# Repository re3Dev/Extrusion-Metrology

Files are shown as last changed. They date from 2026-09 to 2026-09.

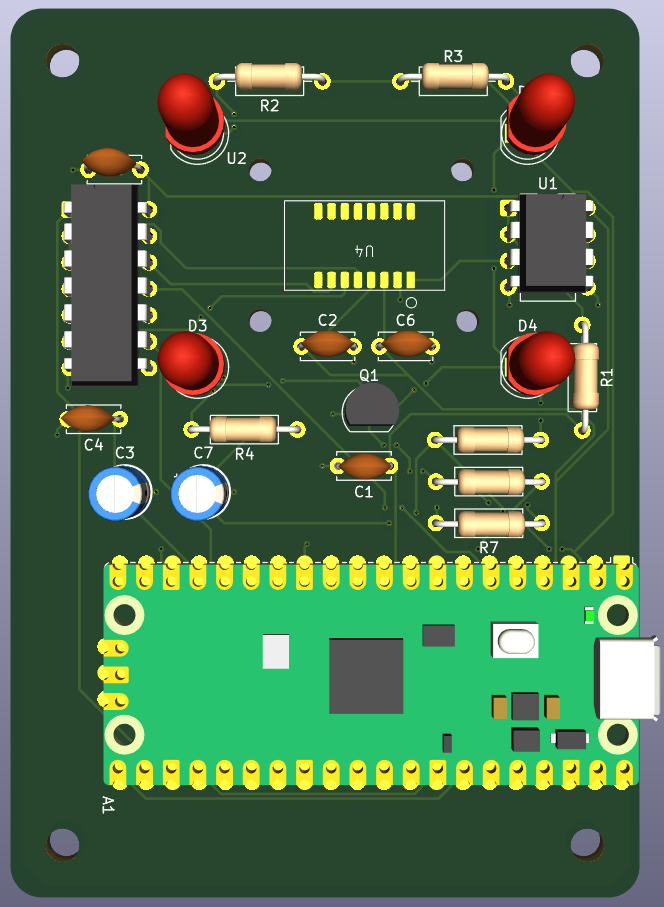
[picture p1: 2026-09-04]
3D-PCB.png

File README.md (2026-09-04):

Copyright © 2026 Mitchell Mashburn All rights reserved.
Source files are made publicly available for review, education, and evaluation. No permission is granted for commercial manufacture, redistribution, or derivative works without written authorization.

# Extrusion-Metrology
PCB with a main purpose of a low-cost, dedicated 1D metrology sensor specifically for a Klipper printer, use controlled illumination to get a high-resolution bead cross-section without running full machine vision, and automate calibration using the printer's existing motion system.

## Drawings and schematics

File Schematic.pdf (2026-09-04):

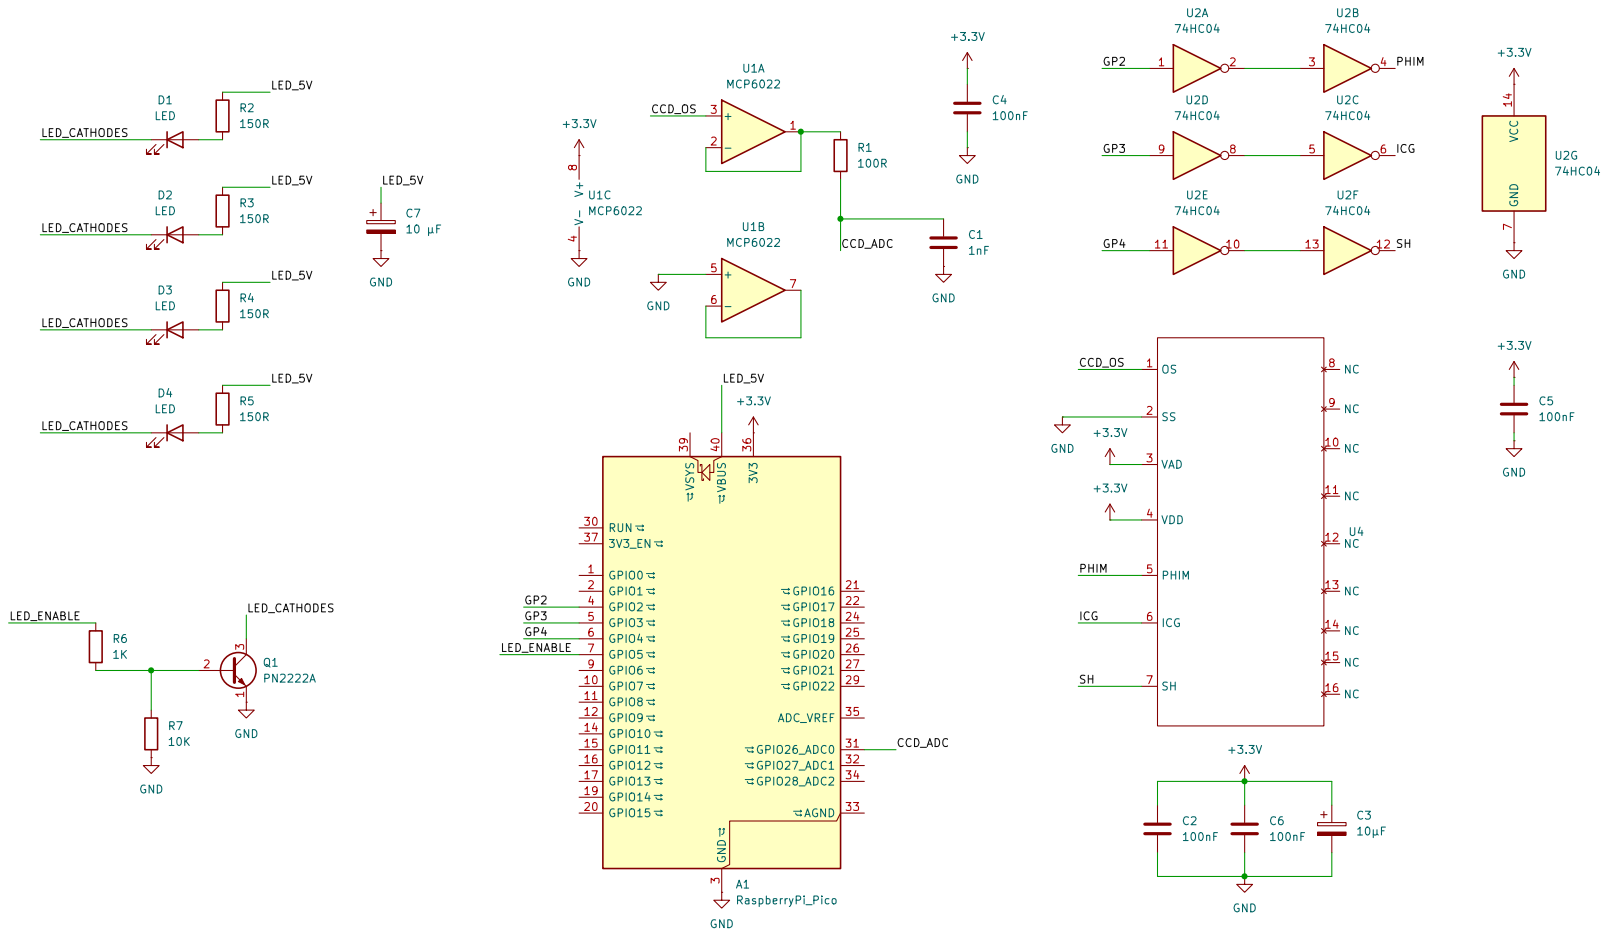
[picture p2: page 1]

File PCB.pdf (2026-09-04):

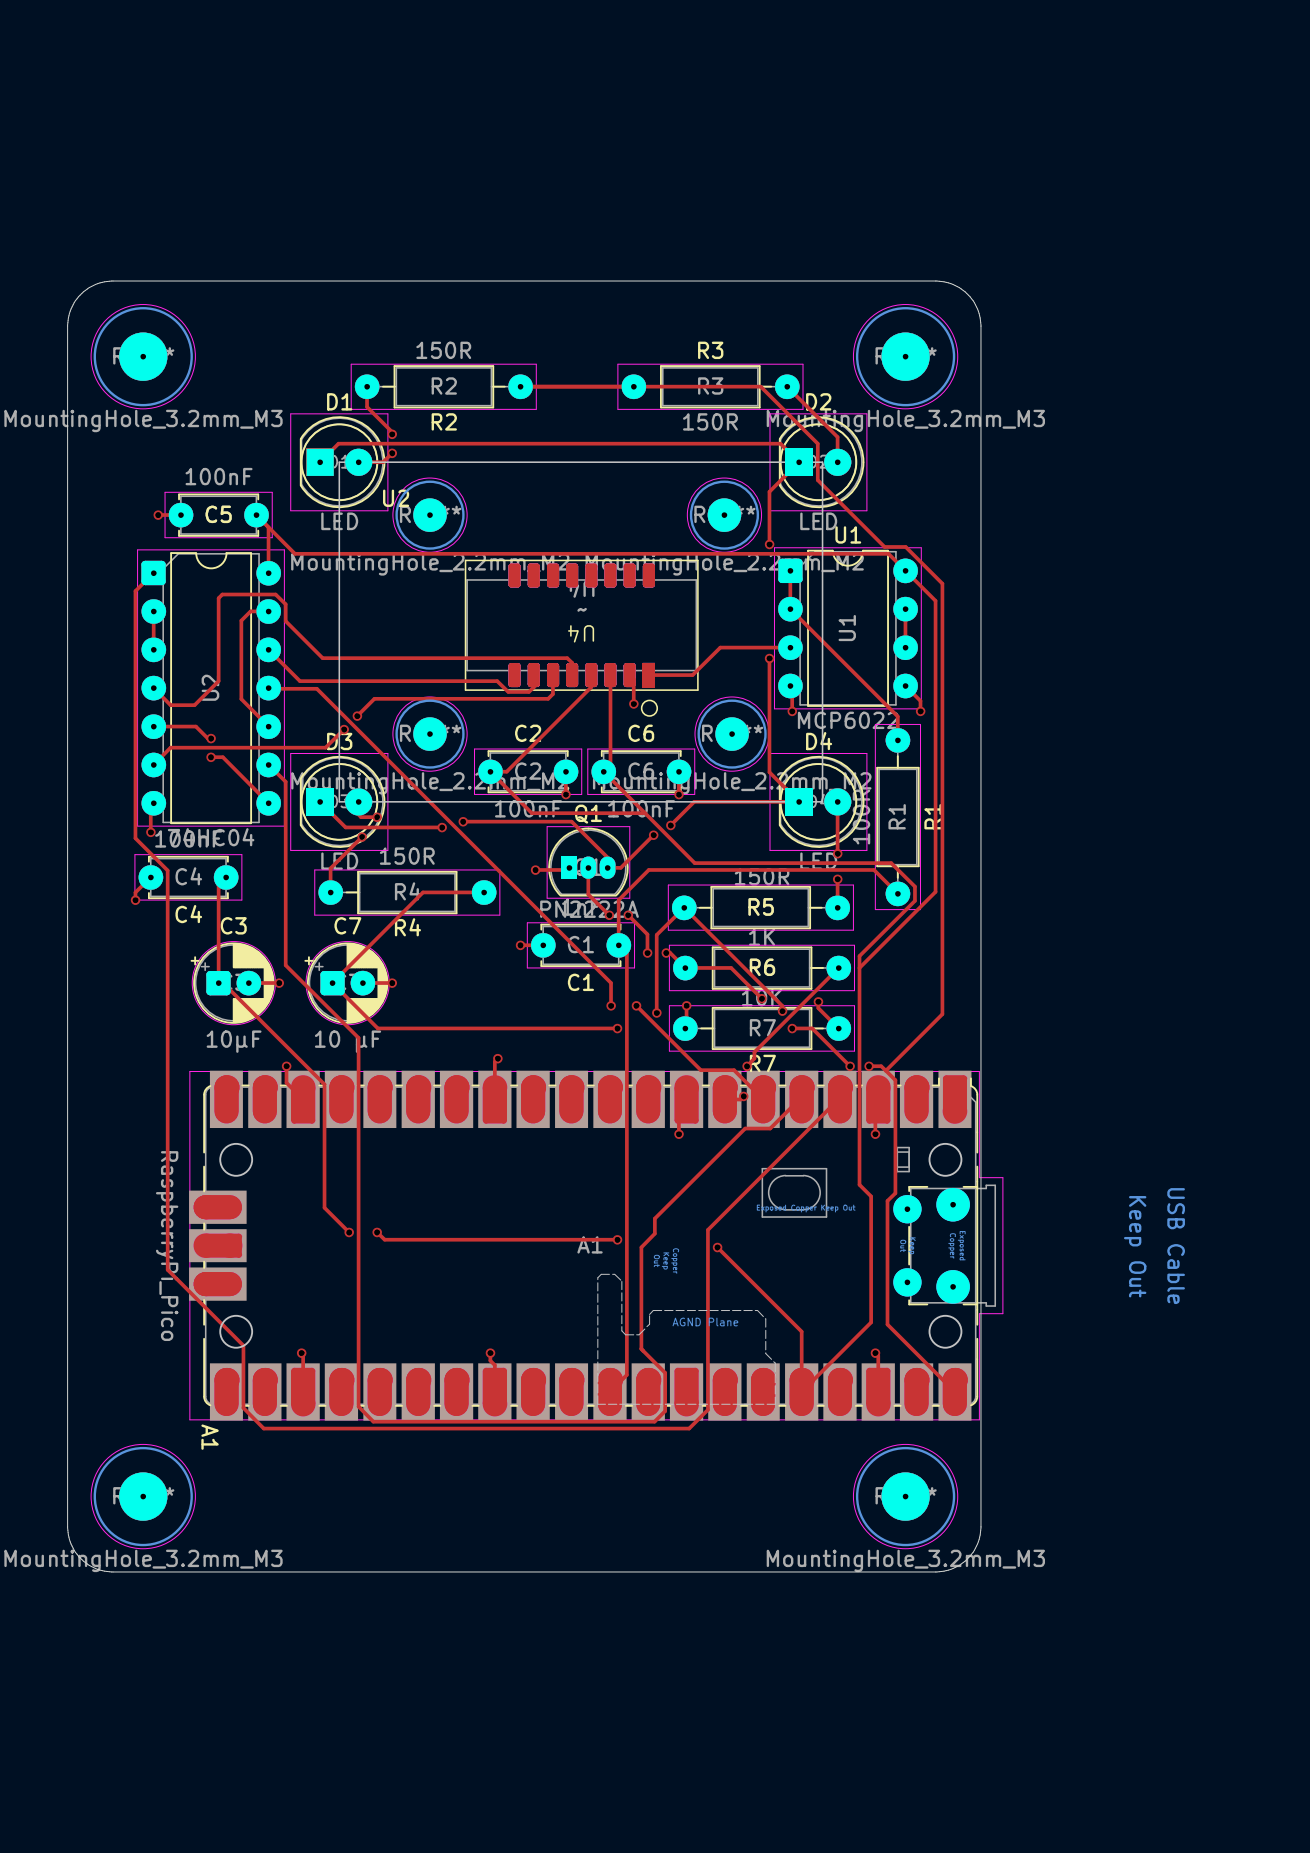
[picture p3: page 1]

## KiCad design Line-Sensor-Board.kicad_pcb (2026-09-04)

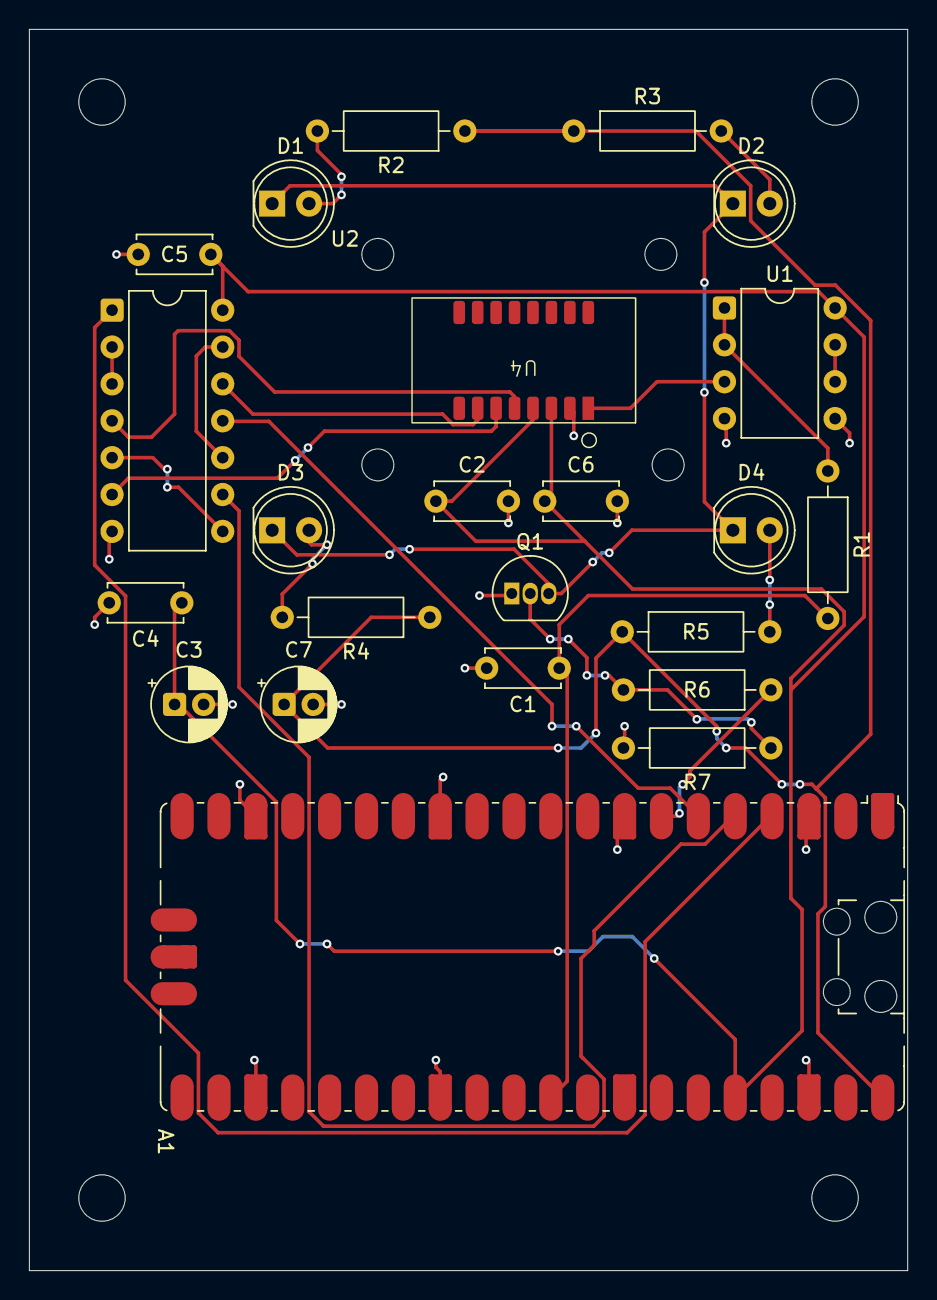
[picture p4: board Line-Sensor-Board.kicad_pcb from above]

Board: 2 copper layers, 60.5 x 85.5 mm, 23 parts (0 on the bottom side), 23 nets.

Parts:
A1: RaspberryPi_Pico; RaspberryPi_Pico_SMD_HandSolder
C1: 1nF; C_Disc_D5.0mm_W2.5mm_P5.00mm
C2, C4, C5, C6: 100nF; C_Disc_D5.0mm_W2.5mm_P5.00mm
C3: 10µF; CP_Radial_D5.0mm_P2.00mm
C7: 10 µF; CP_Radial_D5.0mm_P2.00mm
D1, D2, D3, D4: LED; LED_D5.0mm
Q1: PN2222A; TO-92_Inline
R1: 100R; R_Axial_DIN0207_L6.3mm_D2.5mm_P10.16mm_Horizontal
R2, R3, R4, R5: 150R; R_Axial_DIN0207_L6.3mm_D2.5mm_P10.16mm_Horizontal
R6: 1K; R_Axial_DIN0207_L6.3mm_D2.5mm_P10.16mm_Horizontal
R7: 10K; R_Axial_DIN0207_L6.3mm_D2.5mm_P10.16mm_Horizontal
U1: MCP6022; DIP-8_W7.62mm
U2: 74HC04; DIP-14_W7.62mm
U4: TCD1103GFG_HandSolder

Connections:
+3.3V: A1.36 (3V3), C2.1, C3.1, C4.1, C5.1, C6.1, U1.8 (V+), U2.14 (VCC), U4.3 (VAD), U4.4 (VDD)
/CCD_ADC: A1.31 (GPIO26_ADC0), C1.1, R1.2
/CCD_OS: U1.3 (+), U4.1 (OS)
/GP2: A1.4 (GPIO2), U2.1
/GP3: A1.5 (GPIO3), U2.9
/GP4: A1.6 (GPIO4), U2.11
/ICG: U2.6, U4.6 (ICG)
/LED_5V: A1.40 (VBUS), C7.1, R2.1, R3.1, R4.1, R5.1
/LED_CATHODES: D1.1 (K), D2.1 (K), D3.1 (K), D4.1 (K), Q1.3 (C)
/LED_ENABLE: A1.7 (GPIO5), R6.1
/PHIM: U2.4, U4.5 (PHIM)
/SH: U2.12, U4.7 (SH)
GND: A1.3 (GND), A1.8 (GND), A1.13 (GND), A1.18 (GND), A1.23 (GND), A1.28 (GND), A1.38 (GND), C1.2, C2.2, C3.2, C4.2, C5.2, C6.2, C7.2, Q1.1 (E), R7.2, U1.4 (V-), U1.5 (+), U2.7 (GND), U4.2 (SS)
unnamed: D1.2 (A), R2.2
unnamed: D2.2 (A), R3.2
unnamed: D3.2 (A), R4.2
unnamed: D4.2 (A), R5.2
unnamed: Q1.2 (B), R6.2, R7.1
unnamed: R1.1, U1.1, U1.2 (-)
unnamed: U1.6 (-), U1.7
unnamed: U2.2, U2.3
unnamed: U2.5, U2.8
unnamed: U2.10, U2.13

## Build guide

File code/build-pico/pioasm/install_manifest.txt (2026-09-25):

C:/Users/info/Documents/Extrusion-Metrology/code/build-pico/pioasm-install/pioasm/pioasm.exe
C:/Users/info/Documents/Extrusion-Metrology/code/build-pico/pioasm-install/pioasm/pioasmTargets.cmake
C:/Users/info/Documents/Extrusion-Metrology/code/build-pico/pioasm-install/pioasm/pioasmTargets-release.cmake
C:/Users/info/Documents/Extrusion-Metrology/code/build-pico/pioasm-install/pioasm/pioasmConfig.cmake
C:/Users/info/Documents/Extrusion-Metrology/code/build-pico/pioasm-install/pioasm/pioasmConfigVersion.cmake

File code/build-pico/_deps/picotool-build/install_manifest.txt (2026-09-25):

C:/Users/info/Documents/Extrusion-Metrology/code/build-pico/_deps/picotool/picotool.exe
C:/Users/info/Documents/Extrusion-Metrology/code/build-pico/_deps/picotool/picotoolTargets.cmake
C:/Users/info/Documents/Extrusion-Metrology/code/build-pico/_deps/picotool/picotoolTargets-release.cmake
C:/Users/info/Documents/Extrusion-Metrology/code/build-pico/_deps/picotool/picotoolConfig.cmake
C:/Users/info/Documents/Extrusion-Metrology/code/build-pico/_deps/picotool/picotoolConfigVersion.cmake
C:/Users/info/Documents/Extrusion-Metrology/code/build-pico/_deps/picotool/enc_bootloader.elf
C:/Users/info/Documents/Extrusion-Metrology/code/build-pico/_deps/picotool/enc_bootloader_mbedtls.elf

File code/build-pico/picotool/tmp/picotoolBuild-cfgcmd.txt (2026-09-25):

cmd='C:/Program Files/CMake/bin/cmake.exe;--no-warn-unused-cli;-DCMAKE_MAKE_PROGRAM:FILEPATH=C:/Strawberry/c/bin/ninja.exe;-DPICO_SDK_PATH:FILEPATH=C:/Users/info/.pico-sdk/sdk/2.2.0;-DPICOTOOL_NO_LIBUSB=1;-DPICOTOOL_FLAT_INSTALL=1;-DCMAKE_INSTALL_PREFIX=C:/Users/info/Documents/Extrusion-Metrology/code/build-pico/_deps;-DCMAKE_RULE_MESSAGES=OFF;-DCMAKE_INSTALL_MESSAGE=NEVER;-GNinja;-S;<SOURCE_DIR><SOURCE_SUBDIR>;-B;<BINARY_DIR>'

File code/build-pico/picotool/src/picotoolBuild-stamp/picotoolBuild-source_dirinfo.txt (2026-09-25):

# This is a generated file and its contents are an internal implementation detail.
# The download step will be re-executed if anything in this file changes.
# No other meaning or use of this file is supported.

method=source_dir
command=
source_dir=C:/Users/info/Documents/Extrusion-Metrology/code/build-pico/_deps/picotool-src
work_dir=

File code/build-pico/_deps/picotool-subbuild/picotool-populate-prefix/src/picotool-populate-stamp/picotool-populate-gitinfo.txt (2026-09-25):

# This is a generated file and its contents are an internal implementation detail.
# The download step will be re-executed if anything in this file changes.
# No other meaning or use of this file is supported.

method=git
command=C:/Program Files/CMake/bin/cmake.exe;-DCMAKE_MESSAGE_LOG_LEVEL=VERBOSE;-P;C:/Users/info/Documents/Extrusion-Metrology/code/build-pico/_deps/picotool-subbuild/picotool-populate-prefix/tmp/picotool-populate-gitclone.cmake
source_dir=C:/Users/info/Documents/Extrusion-Metrology/code/build-pico/_deps/picotool-src
work_dir=C:/Users/info/Documents/Extrusion-Metrology/code/build-pico/_deps
repository=https://github.com/raspberrypi/picotool.git
remote=origin
init_submodules=TRUE
recurse_submodules=--recursive
submodules=
CMP0097=NEW

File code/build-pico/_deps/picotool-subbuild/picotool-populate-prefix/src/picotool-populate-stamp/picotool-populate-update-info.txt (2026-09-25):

# This is a generated file and its contents are an internal implementation detail.
# The patch step will be re-executed if anything in this file changes.
# No other meaning or use of this file is supported.

command (connected)=C:/Program Files/CMake/bin/cmake.exe;-Dcan_fetch=YES;-DCMAKE_MESSAGE_LOG_LEVEL=VERBOSE;-P;C:/Users/info/Documents/Extrusion-Metrology/code/build-pico/_deps/picotool-subbuild/picotool-populate-prefix/tmp/picotool-populate-gitupdate.cmake
command (disconnected)=C:/Program Files/CMake/bin/cmake.exe;-Dcan_fetch=NO;-DCMAKE_MESSAGE_LOG_LEVEL=VERBOSE;-P;C:/Users/info/Documents/Extrusion-Metrology/code/build-pico/_deps/picotool-subbuild/picotool-populate-prefix/tmp/picotool-populate-gitupdate.cmake
work_dir=C:/Users/info/Documents/Extrusion-Metrology/code/build-pico/_deps/picotool-src

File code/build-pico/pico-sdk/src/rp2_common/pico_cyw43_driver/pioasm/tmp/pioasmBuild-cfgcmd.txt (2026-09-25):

cmd='C:/Program Files/CMake/bin/cmake.exe;--no-warn-unused-cli;-DCMAKE_MAKE_PROGRAM:FILEPATH=C:/Strawberry/c/bin/ninja.exe;-DPIOASM_FLAT_INSTALL=1;-DCMAKE_INSTALL_PREFIX=C:/Users/info/Documents/Extrusion-Metrology/code/build-pico/pioasm-install;-DCMAKE_RULE_MESSAGES=OFF;-DCMAKE_INSTALL_MESSAGE=NEVER;-GNinja;-C<TMP_DIR>/pioasmBuild-cache-$<CONFIG>.cmake;-S;<SOURCE_DIR><SOURCE_SUBDIR>;-B;<BINARY_DIR>'

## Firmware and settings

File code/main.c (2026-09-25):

#include <stdint.h>
#include <stdio.h>

#include "pico/stdlib.h"
#include "pico/stdio_usb.h"
#include "hardware/adc.h"

#define PIN_PHIM 2
#define PIN_ICG  3
#define PIN_SH   4
#define PIN_LED  5

#define ADC_GPIO    26
#define ADC_CHANNEL 0

#define CCD_PERIODS        1546
#define ACTIVE_PIXEL_START 32
#define TEST_PIXELS        1500

#define PHIM_HALF_PERIOD_US 1
#define ICG_TO_SH_CYCLES    63
#define EXPOSURE_COUNT       1
#define EXPOSURE_HOLD_FRAMES 1
#define SAMPLE_PHASE         0
#define SH_PERIOD_US         12
#define SH_HIGH_US           4
#define SH_LOW_US            (SH_PERIOD_US - SH_HIGH_US)
#define SH_HIGH_CLOCKS       (SH_HIGH_US / (2 * PHIM_HALF_PERIOD_US))
#define SH_LOW_CLOCKS        (SH_LOW_US / (2 * PHIM_HALF_PERIOD_US))
#define CLEAR_TIME_US        50000

static uint16_t profile[TEST_PIXELS];
static const uint32_t exposure_us[EXPOSURE_COUNT] = {
    100
};

static void setup_sensor_gpio(void)
{
    const uint pins[] = {
        PIN_PHIM,
        PIN_ICG,
        PIN_SH,
        PIN_LED
    };

    for (uint i = 0; i < count_of(pins); i++)
    {
        gpio_init(pins[i]);
        gpio_set_dir(pins[i], GPIO_OUT);
    }

    gpio_put(PIN_PHIM, 1);
    gpio_put(PIN_ICG, 1);
    gpio_put(PIN_SH, 0);
    gpio_put(PIN_LED, 1);
}

static void setup_adc(void)
{
    adc_init();
    adc_gpio_init(ADC_GPIO);
    adc_select_input(ADC_CHANNEL);
    adc_fifo_setup(false, false, 1, false, false);
    adc_set_clkdiv(0.0f);
}

static void clock_phim_cycle(void)
{
    gpio_put(PIN_PHIM, 0);
    busy_wait_us_32(PHIM_HALF_PERIOD_US);

    gpio_put(PIN_PHIM, 1);
    busy_wait_us_32(PHIM_HALF_PERIOD_US);
}

static void start_adc_conversion(void)
{
    hw_set_bits(
        &adc_hw->cs,
        ADC_CS_START_ONCE_BITS
    );
}

static uint16_t finish_adc_conversion(void)
{
    while (!(adc_hw->cs & ADC_CS_READY_BITS))
    {
        tight_loop_contents();
    }

    return (uint16_t) adc_hw->result;
}

static uint16_t clock_and_sample_period(uint sample_phase)
{
    gpio_put(PIN_PHIM, 0);

    if (sample_phase == 0)
    {
        start_adc_conversion();
    }

    busy_wait_us_32(PHIM_HALF_PERIOD_US);

    gpio_put(PIN_PHIM, 1);

    if (sample_phase == 1)
    {
        start_adc_conversion();
    }

    busy_wait_us_32(PHIM_HALF_PERIOD_US);

    gpio_put(PIN_PHIM, 0);

    if (sample_phase == 2)
    {
        start_adc_conversion();
    }

    busy_wait_us_32(PHIM_HALF_PERIOD_US);

    gpio_put(PIN_PHIM, 1);

    if (sample_phase == 3)
    {
        start_adc_conversion();
    }

    busy_wait_us_32(PHIM_HALF_PERIOD_US);

    return finish_adc_conversion();
}

static void transfer_sensor_line(void)
{
    gpio_put(PIN_PHIM, 1);
    gpio_put(PIN_ICG, 0);

    // 63 cycles is approximately 500 ns at the default 125 MHz sys clock.
    busy_wait_at_least_cycles(ICG_TO_SH_CYCLES);

    gpio_put(PIN_SH, 1);

    for (uint cycle = 0;
         cycle < SH_HIGH_CLOCKS;
         cycle++)
    {
        clock_phim_cycle();
    }

    gpio_put(PIN_SH, 0);
    clock_phim_cycle();
    clock_phim_cycle();
    clock_phim_cycle();

    // clock_phim_cycle() returns with PHIM high, as required for ICG rising.
    gpio_put(PIN_ICG, 1);
    clock_phim_cycle();
}

static void clear_sensor_charge(void)
{
    uint32_t shutter_cycles =
        CLEAR_TIME_US / SH_PERIOD_US;

    gpio_put(PIN_ICG, 1);

    for (uint32_t pulse = 0;
         pulse < shutter_cycles;
         pulse++)
    {
        gpio_put(PIN_SH, 1);

        for (uint cycle = 0;
             cycle < SH_HIGH_CLOCKS;
             cycle++)
        {
            clock_phim_cycle();
        }

        gpio_put(PIN_SH, 0);

        for (uint cycle = 0;
             cycle < SH_LOW_CLOCKS;
             cycle++)
        {
            clock_phim_cycle();
        }
    }
}

static void capture_line(
    uint sample_phase,
    uint32_t integration_us
)
{
    // Repeated SH pulses clear charge while ICG remains high.
    clear_sensor_charge();

    // The deliberately longer SH-to-SH gap is the selected TINT interval.
    uint32_t integration_clocks =
        integration_us
        / (2 * PHIM_HALF_PERIOD_US);

    for (uint32_t cycle = 0;
         cycle < integration_clocks;
         cycle++)
    {
        clock_phim_cycle();
    }

    // End TINT and transfer the integrated line. This SH pulse has the same
    // width as all electronic-shutter pulses.
    transfer_sensor_line();

    for (int period = 0; period < CCD_PERIODS; period++)
    {
        // Continue the regular SH cycle during readout with ICG high.
        if ((period % 3) == 0)
        {
            gpio_put(PIN_SH, 1);
        }
        else
        {
            gpio_put(PIN_SH, 0);
        }

        uint16_t sample =
            clock_and_sample_period(sample_phase);
        int active_pixel = period - ACTIVE_PIXEL_START;

        if (active_pixel >= 0 && active_pixel < TEST_PIXELS)
        {
            profile[active_pixel] = sample;
        }
    }

    gpio_put(PIN_SH, 0);
}

static void print_profile(uint32_t integration_us)
{
    static const uint8_t frame_magic[4] = {
        'T', 'C', 'D', '1'
    };
    const uint16_t pixel_count = TEST_PIXELS;

    fwrite(frame_magic, sizeof(frame_magic), 1, stdout);
    fwrite(&integration_us, sizeof(integration_us), 1, stdout);
    fwrite(&pixel_count, sizeof(pixel_count), 1, stdout);
    fwrite(profile, sizeof(profile), 1, stdout);
    fflush(stdout);
}

int main(void)
{
    stdio_init_all();
    stdio_set_translate_crlf(&stdio_usb, false);
    sleep_ms(2000);

    setup_sensor_gpio();
    setup_adc();

    uint exposure_index = 0;
    uint exposure_frame = 0;

    while (true)
    {
        uint32_t integration_us =
            exposure_us[exposure_index];

        capture_line(
            SAMPLE_PHASE,
            integration_us
        );
        print_profile(integration_us);

        exposure_frame++;

        if (exposure_frame == EXPOSURE_HOLD_FRAMES)
        {
            exposure_frame = 0;
            exposure_index =
                (exposure_index + 1)
                % EXPOSURE_COUNT;
        }

        sleep_ms(20);
    }
}

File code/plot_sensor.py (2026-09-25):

import serial
from serial import SerialException
import matplotlib.pyplot as plt
import numpy as np
from threading import Event, Lock, Thread
from time import perf_counter

plt.style.use("dark_background")


# --------------------------------------------------
# SETTINGS
# --------------------------------------------------

PORT = "COM3"       # CHANGE THIS
BAUD = 115200

EXPECTED_PIXELS = 1500
FRAME_MAGIC = b"TCD1"
FRAME_HEADER_SIZE = 10
FRAME_SIZE = FRAME_HEADER_SIZE + EXPECTED_PIXELS * 2
SMOOTHING_WINDOW = 21
NOISE_FLOOR = 8
REFERENCE_FRAMES = 20
NOISE_MULTIPLIER = 3.0
HISTORY_FRAMES = 120
HISTORY_DOWNSAMPLE = 3
EDGE_THRESHOLD = 10
MAX_EDGE_GAP = 4
MIN_OBJECT_WIDTH = 5
GUI_INTERVAL_MS = 20
DISPLAY_SCALE = 250.0


# --------------------------------------------------
# SERIAL
# --------------------------------------------------

ser = serial.Serial(
    PORT,
    BAUD,
    timeout=0.1
)

print("Connected to", PORT)
frame_lock = Lock()
stop_event = Event()
latest_packet = None
latest_sequence = 0
connection_error = None


# --------------------------------------------------
# GRAPH
# --------------------------------------------------

x = np.arange(EXPECTED_PIXELS)
current_exposure = None
reference = None
reference_frames = []
noise_threshold = np.full(EXPECTED_PIXELS, NOISE_FLOOR, dtype=float)
displayed_change = np.zeros(EXPECTED_PIXELS)
history = np.zeros((
    HISTORY_FRAMES,
    EXPECTED_PIXELS // HISTORY_DOWNSAMPLE
))
processed_sequence = 0
last_frame_time = None
display_fps = 0.0

fig, (profile_ax, history_ax) = plt.subplots(
    2,
    1,
    figsize=(13, 8),
    height_ratios=(1, 2),
    sharex=True
)
fig.patch.set_facecolor("#0d1117")

for axis in (profile_ax, history_ax):
    axis.set_facecolor("#161b22")
    axis.tick_params(colors="#c9d1d9")
    axis.xaxis.label.set_color("#c9d1d9")
    axis.yaxis.label.set_color("#c9d1d9")
    axis.title.set_color("#f0f6fc")

    for spine in axis.spines.values():
        spine.set_color("#30363d")

profile_line, = profile_ax.plot(
    x,
    displayed_change,
    linewidth=2,
    color="#e4572e"
)
profile_ax.axhline(
    EDGE_THRESHOLD,
    color="#777777",
    linestyle="--",
    linewidth=1
)
left_edge_line = profile_ax.axvline(
    0,
    color="#00d4ff",
    linewidth=2,
    visible=False
)
right_edge_line = profile_ax.axvline(
    0,
    color="#7cff6b",
    linewidth=2,
    visible=False
)

profile_ax.set_title("Live Object Profile")
profile_ax.set_ylabel("Signal")
profile_ax.set_xlim(0, EXPECTED_PIXELS - 1)
profile_ax.set_ylim(0, DISPLAY_SCALE)
profile_ax.grid(True, color="#30363d", alpha=0.7)

history_image = history_ax.imshow(
    history,
    aspect="auto",
    origin="upper",
    extent=(0, EXPECTED_PIXELS - 1, HISTORY_FRAMES, 0),
    cmap="inferno",
    vmin=0,
    vmax=DISPLAY_SCALE,
    interpolation="nearest"
)
history_ax.set_title("Sweep History (Newest Frame at Top)")
history_ax.set_xlabel("Active pixel")
history_ax.set_ylabel("Frames ago")
colorbar = fig.colorbar(history_image, ax=history_ax, pad=0.01)
colorbar.set_label("Object signal")
colorbar.ax.tick_params(colors="#c9d1d9")
colorbar.ax.yaxis.label.set_color("#c9d1d9")
colorbar.outline.set_edgecolor("#30363d")

status_text = profile_ax.text(
    0.99,
    0.93,
    "Learning scene",
    transform=profile_ax.transAxes,
    horizontalalignment="right",
    verticalalignment="top",
    color="#f0f6fc",
    bbox={
        "facecolor": "#0d1117",
        "edgecolor": "#30363d",
        "alpha": 0.85,
        "pad": 4
    }
)

fig.tight_layout()


# --------------------------------------------------
# UPDATE
# --------------------------------------------------

def smooth_profile(values):

    radius = SMOOTHING_WINDOW // 2
    padded = np.pad(values, radius, mode="edge")
    kernel = np.full(SMOOTHING_WINDOW, 1.0 / SMOOTHING_WINDOW)
    return np.convolve(padded, kernel, mode="valid")


def find_object_edges(signal):

    active = signal >= EDGE_THRESHOLD
    inactive = np.flatnonzero(~active)

    for start, end in zip(inactive[:-1], inactive[1:]):
        if 1 < end - start <= MAX_EDGE_GAP + 1:
            active[start + 1:end] = True

    transitions = np.diff(
        np.pad(active.astype(np.int8), (1, 1))
    )
    starts = np.flatnonzero(transitions == 1)
    ends = np.flatnonzero(transitions == -1) - 1
    candidates = [
        (left, right)
        for left, right in zip(starts, ends)
        if right - left + 1 >= MIN_OBJECT_WIDTH
    ]

    if not candidates:
        return None

    return max(
        candidates,
        key=lambda edges: np.sum(signal[edges[0]:edges[1] + 1])
    )


def reset_reference(event=None):

    global reference, reference_frames, noise_threshold
    global displayed_change, history

    if event is None or event.key.lower() == "r":
        reference = None
        reference_frames = []
        noise_threshold.fill(NOISE_FLOOR)
        displayed_change.fill(0)
        history.fill(0)
        profile_line.set_ydata(displayed_change)
        history_image.set_data(history)
        left_edge_line.set_visible(False)
        right_edge_line.set_visible(False)
        status_text.set_text("Learning scene")


fig.canvas.mpl_connect("key_press_event", reset_reference)


def read_sensor_frames():

    global latest_packet, latest_sequence, connection_error
    buffer = bytearray()

    while not stop_event.is_set():
        try:
            chunk = ser.read(max(ser.in_waiting, 1))
        except SerialException as error:
            connection_error = str(error)
            return

        if not chunk:
            continue

        buffer.extend(chunk)

        while True:
            magic_index = buffer.find(FRAME_MAGIC)
            if magic_index < 0:
                del buffer[:-3]
                break

            if magic_index:
                del buffer[:magic_index]

            if len(buffer) < FRAME_SIZE:
                break

            exposure = int.from_bytes(buffer[4:8], "little")
            pixel_count = int.from_bytes(buffer[8:10], "little")
            if pixel_count != EXPECTED_PIXELS:
                del buffer[0]
                continue

            values = np.frombuffer(
                buffer,
                dtype="<u2",
                count=EXPECTED_PIXELS,
                offset=FRAME_HEADER_SIZE
            ).copy()
            del buffer[:FRAME_SIZE]

            with frame_lock:
                latest_packet = (exposure, values, perf_counter())
                latest_sequence += 1
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
